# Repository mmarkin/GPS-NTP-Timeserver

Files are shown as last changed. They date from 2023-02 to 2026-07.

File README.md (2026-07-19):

# GPS-NTP-Timeserver
WiFi enabled GPS fed NTP server based on ESP8266 and Arduino framework 

This project adds to the work of Cristiano Monteiro's original GPS-fed NTP timeserver.    
Here is a link to a repository detailing his updated portable version.    
https://github.com/Montecri/GPSTimeServer

I added a second OLED display to show information about what is connected to the server. I also built a custom enclosure for my version 
using walnut, ABS, and tinted transparent acrylic. I tried using a solid wood top but it reduced the GPS reception. The top's ABS panel doesn't 
affect the GPS or WiFi signals. 

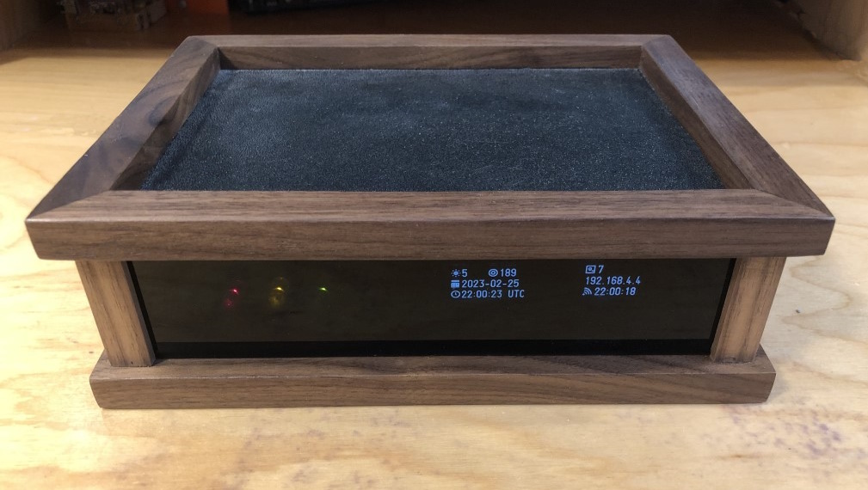
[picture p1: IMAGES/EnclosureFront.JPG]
EnclosureFront_bb-menor


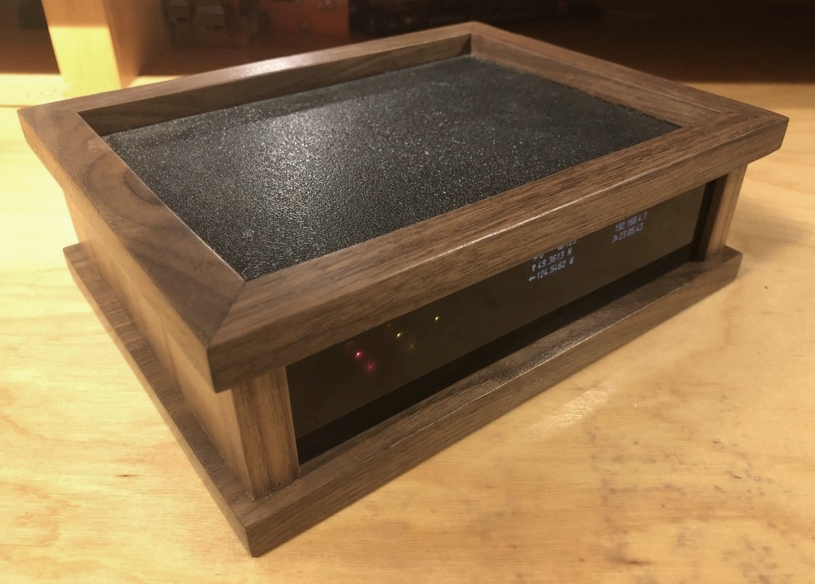
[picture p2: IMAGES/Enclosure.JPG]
Enclosure_bb-menor


As on Cristiano's original version, the first OLED display shows the number of GPS satellites that are "in view," the resolution 
of the position fix, and the UTC time and date. The second OLED display helps to verify that the server responds to the NTP requests. 
Every time an NTP request comes in from a client, i.e., a clock connected to the server's WiFi network, its IP address and the time 
the response was sent are shown on the display. This information remains on the display until the next request arrives. It also shows 
the total number of clients connected. In server mode, ESP8266 microcontrollers can handle up to eight WiFi clients.

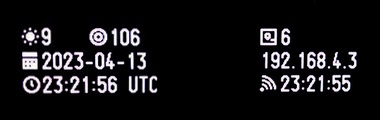
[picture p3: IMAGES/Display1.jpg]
Display1_bb-menor


This version adds a switch so the first display can also show the latitude and longitude. This time server is GPS-based so it 
might as well be able to show where it is located (the exact location has been fuzzed out in the photo). If the location was 
in the southern or eastern hemispheres the arrows would point the opposite way.

Display3_bb-menor

The switch can also turn the displays off since OLED displays can wear out if they are active all the time, especially if they 
show information that doesn't change much. See the schematic diagram below for more details.    

The second display is optional, the code posted here runs without it. However, with multiple clocks it's a handy way to 
make sure they are all connected and being served. 

The I2C address of the second OLED module has to be changed. This is done by relocating a resistor on the module's circuit
board. There is a graphic on the board to show which resistor it is and where it goes for each of the two addresses. For example,
with the recommended SSD1306 modules the address is changed from 0x78 to 0x7A. The resistor is a tiny surface-mount part so 
it requires a bit of delicate soldering to make the change. Also once it's free be careful not to lose it. Don't ask how I know!

The U8g2 library the code uses to drive the OLED displays works with many different displays. 
You just need to use the constructor from the library and the I2C addresses that match the displays being used.
For example, SH1106 modules could also be used. Object definitions for SH1106 modules are included in the definitions.h file. 
To use them comment out the SSD1306 definitions and uncomment the SH1106 definitions. 
The I2C addresses specified in the code may also need to be changed to 0x3C and 0x3D. 

As on Cristiano's original version, the red LED flashes every second when GPS data is available.
The yellow LED shows that WiFi is enabled. The green LED shows that the GPS data is valid and the server's 
internal clock is synchronized with it.

IMG_3050_MOV_AdobeExpress

To use the server, set the clock so it joins the WiFi network specified by the SSID and password in the definitions.h 
file. Also set the clock so the address for the time server it calls is 192.168.4.1 which is the default IP address ESP 
devices use in server mode. The server will assign IP addresses to clients on its network starting with 192.168.4.2.

It is highly recommended to use PlatformIO to compile and edit the code. That way all the libraries needed will be 
downloaded and installed automatically. For those not familiar with PlatformIO, it runs as an extension for Microsoft's VS Code. 
Both are free to download and use without restriction like the Arduino IDE. However, PlatformIO has more professional features 
that make it easier to develop a project like this once you get the hang of using it.
All the files needed for this project have been provided. The code is in two files: definitions.h is in the "includes" directory 
and main.cpp is in the "src" directory. The platformio.ini file is also provided.   

Having said that, the Arduino IDE <i>can</i> be used if desired. Instructions are in the "Using Arduino IDE" file in the "resources" directory.

Parts list:

- Amica NodeMCU (ESP8266 / ESP-12)                   
- DS3231 RTC
- U-blox Neo-6m V2 GPS
- 0.96" OLED Display (SSD1306 or similar. 
  If two are used be sure that it is possible to change the I2C address on one of them.) 
- Hi-Link 5V/3W Power supply
- Mini-360 DC-DC Buck converter
- Red, Green and Yellow LEDs
- Resistors (150, 100 and 150 Ohms respectively for above LEDs)
- Momentary push button switch
- SPDT center off toggle switch

---
<p align="center">  
<b>ATTENTION</b> </p> 

Several DS3231 modules being sold today contain a hazardous design flaw in which it supplies a voltage to the battery cradle 
regardless if it came with a rechargeable battery or not. 
If it came with a CR2032 battery (non-rechargeable) the consequence is that it will swell, explode, or worse. 
If it came with an LIR2032 battery (rechargeable) and the module is fed with 5v, that will generate an unsafe charging voltage for 
that battery.

There are workarounds for this so you do not need to toss your module away, the most popular being the removal of a diode and/or 
resistor.

There is a long discussion on the thread below about the root cause and possible fixes:

https://forum.arduino.cc/t/zs-042-ds3231-rtc-module/268862/33

---

Libraries:

- paulstoffregen/Time@^1.6
- makuna/RTC@^2.4.3
- mikalhart/TinyGPS@0.0.0-alpha+sha.db4ef9c97a
- olikraus/U8g2@^2.28.8

Source code is also based on:<br>
- http://w8bh.net/avr/clock2.pdf
- https://forum.arduino.cc/t/ntp-time-server/192816
- http://www.brettoliver.org.uk/GPS_Time_Server/GPS_Time_Server.htm
- https://www.brettoliver.org.uk/GPS_Time_Server/GPS_Time_Server_v2.htm

---

Schematic diagram

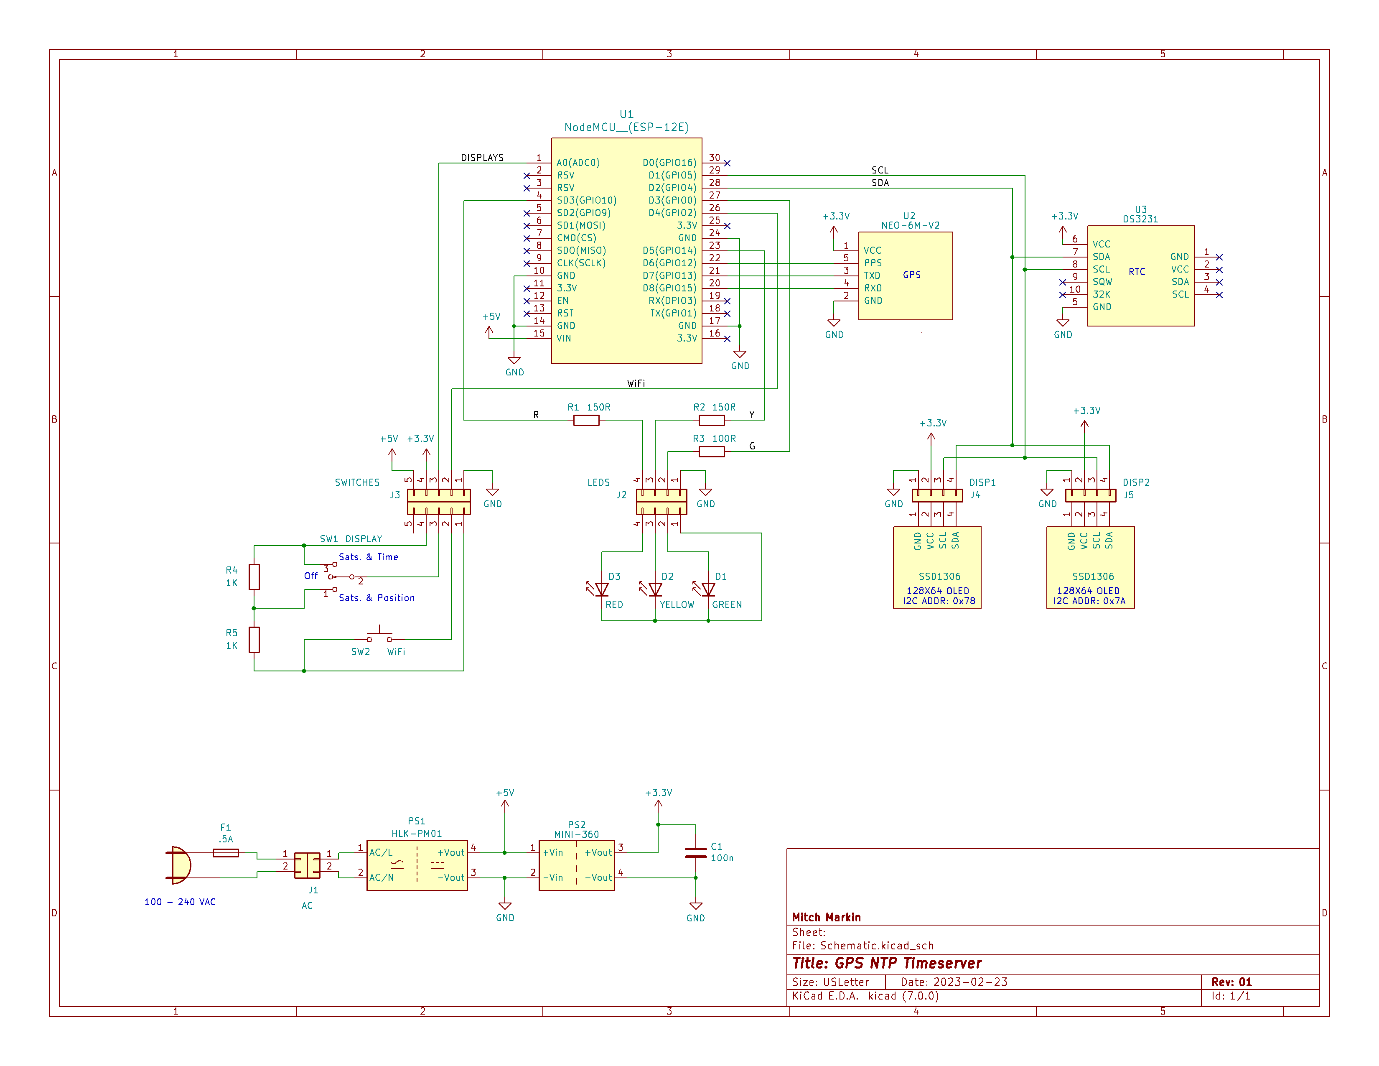
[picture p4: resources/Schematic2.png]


Breadboard layout

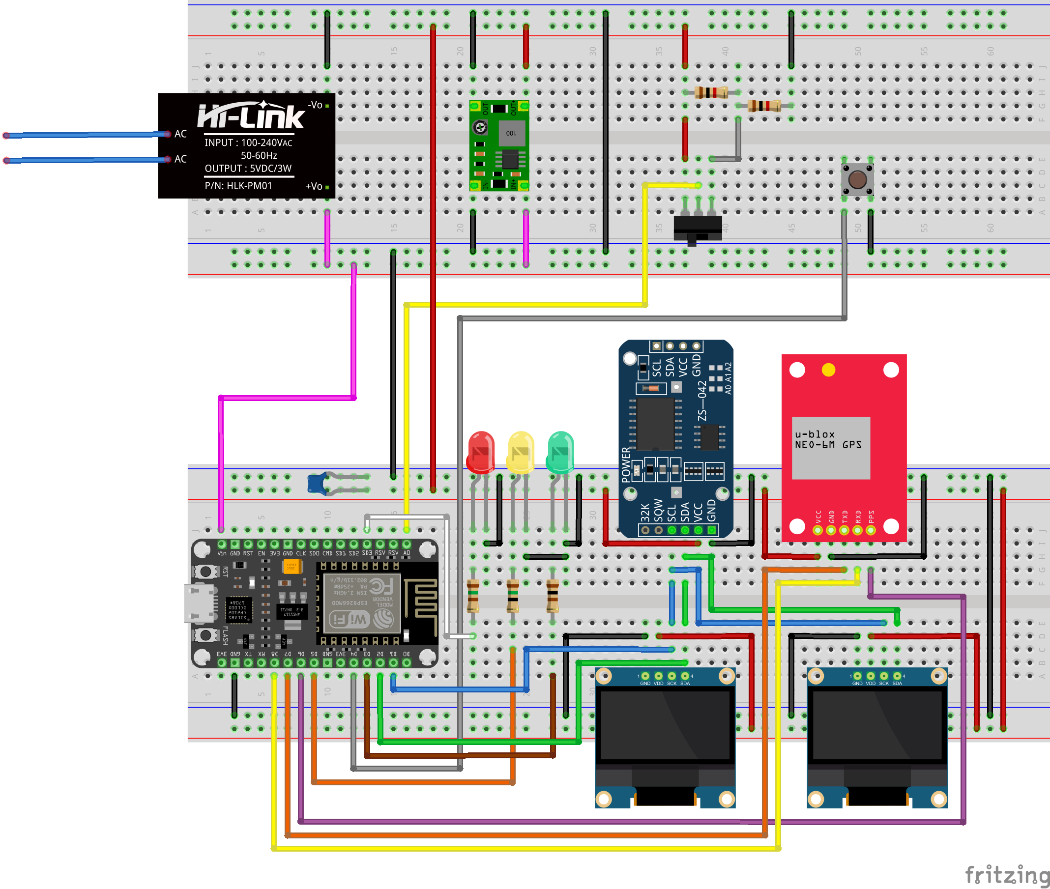
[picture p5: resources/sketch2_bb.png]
sketch_bb-menor


I designed a printed circuit board for the project and had a few made. The Gerber files are in the "resources" folder.
NodeMCU modules come in various sizes. The board was designed for a module that has a 22.86mm (.9 inch) pitch between 
the two rows of pins such as the specified Amica module.  

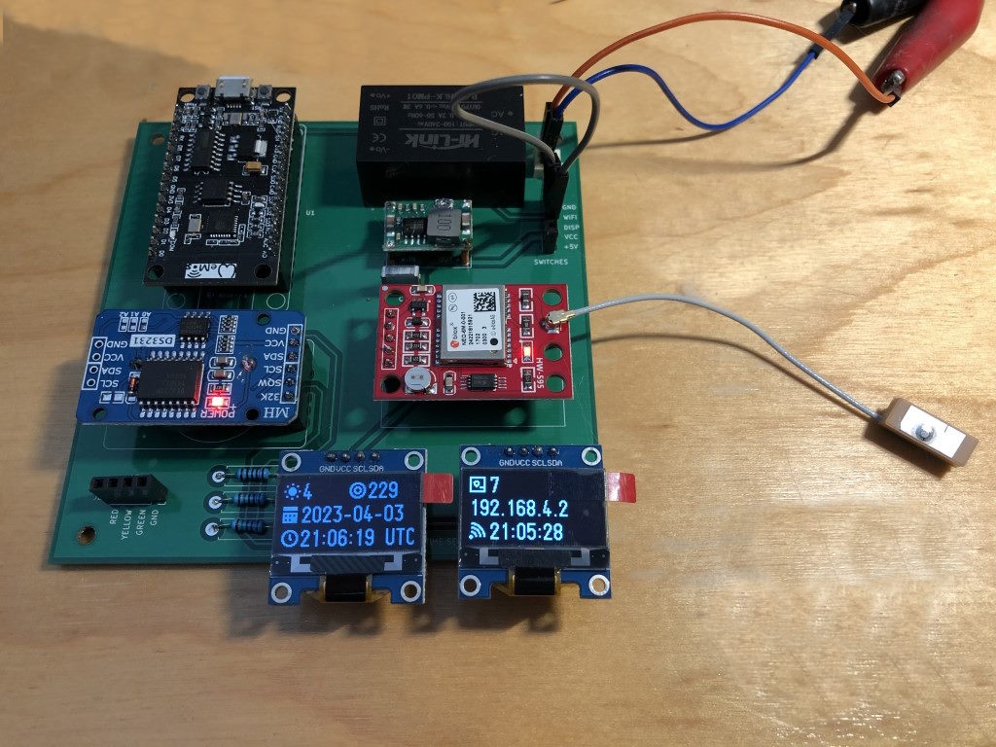
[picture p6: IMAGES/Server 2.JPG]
server2_bb-menor


Here are a couple of photos of the interior of the enclosure.

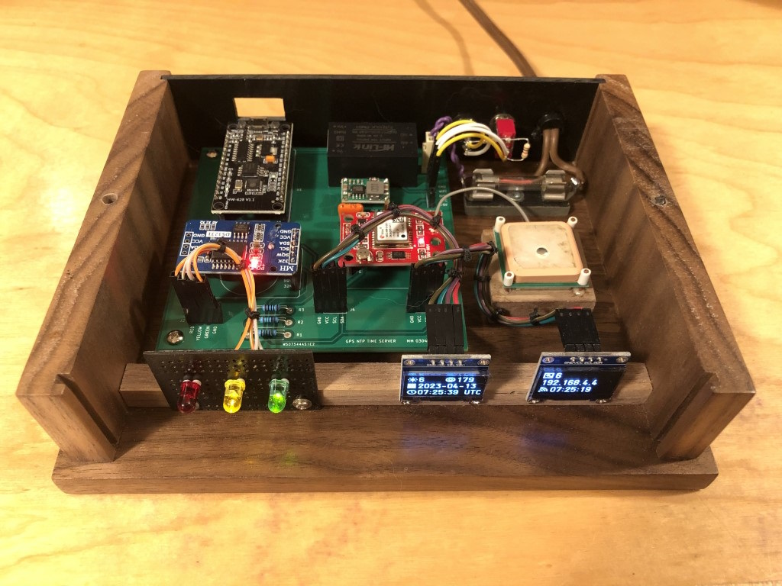
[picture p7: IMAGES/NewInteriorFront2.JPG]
intFront_bb-menor


With the antenna shown the GPS reception is good even indoors not near a window on the ground floor of a two-story 
wood frame building.

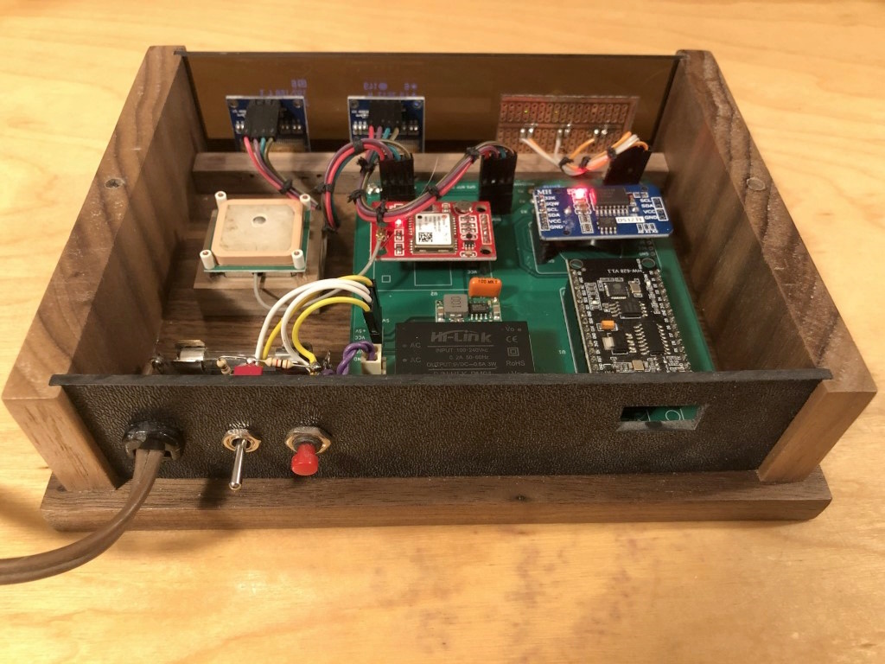
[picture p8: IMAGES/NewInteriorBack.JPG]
intBack_bb-menor


The push button enables or disables the WiFi. It's not really needed here and it could be omitted along with the yellow LED. 
They are carry-overs from Cristiano's version which can be battery-powered, so they are there to conserve power when WiFi isn't needed.
This version is AC-powered and WiFi is enabled by default.
The toggle switch is SPDT with a center-off position. It selects whether time/date/satellite information or the latitude/longitude
received from GPS is shown on the first OLED display. It also turns the displays on and off.

There is also a branch on this repository called PIR Version. It shows a version of this project where a PIR
(passive infrared) module is used to enable both OLED displays only when it detects someone is nearby. 
The pushbutton in that version enables or disables WiFi as usual, 
but a long press switches the first display between time/date/satellite information and the latitude/longitude received from GPS. 

CAD drawing for the enclosure

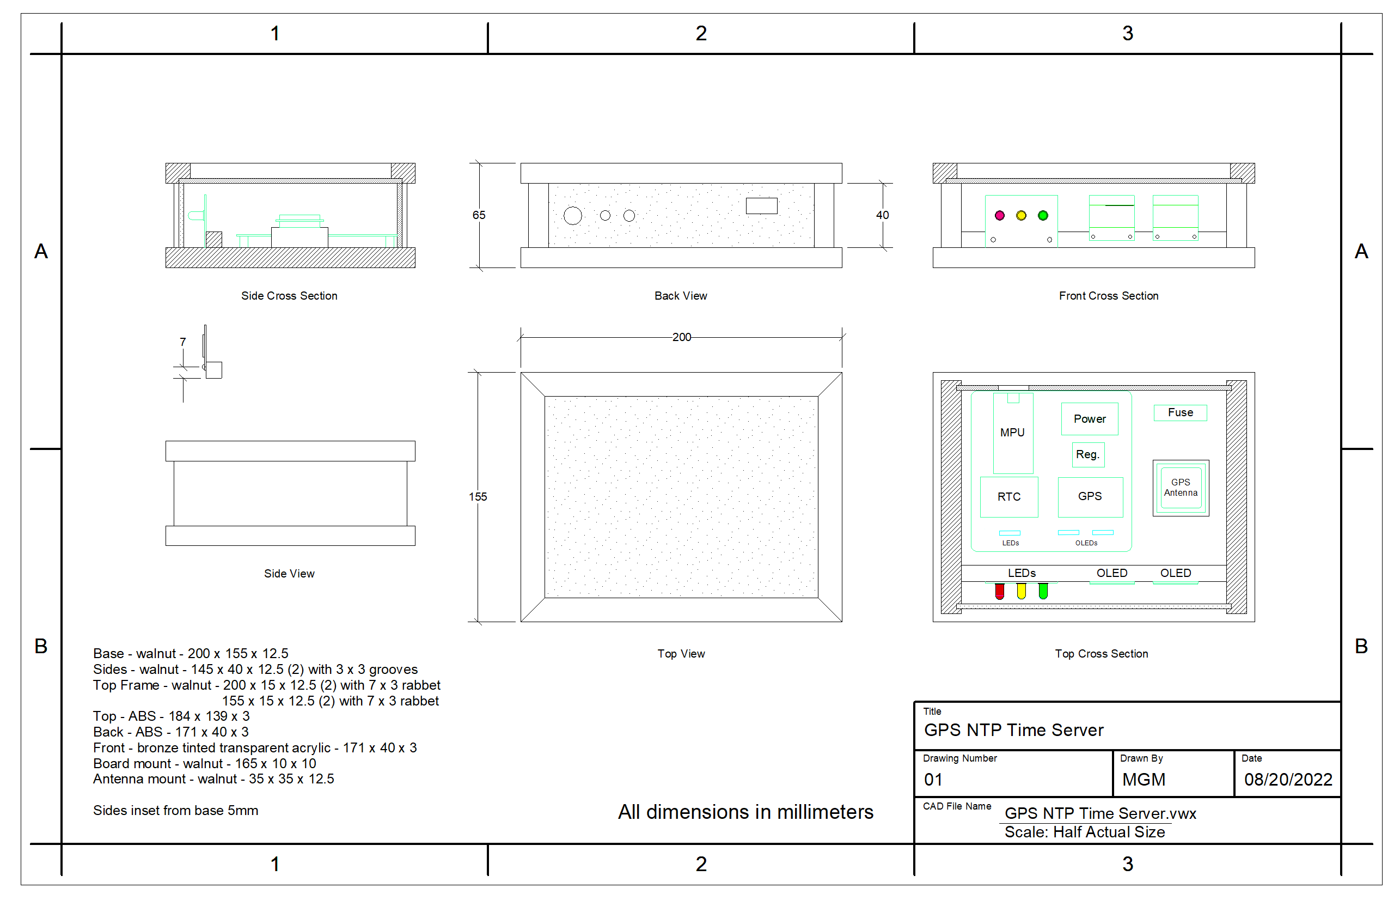
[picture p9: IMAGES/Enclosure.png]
CAD-_bb-menor


More information about Cristiano's original version of this timeserver can be found here:<br>
https://www.linkedin.com/pulse/iot-maker-tale-stratum-1-time-server-built-from-scratch-monteiro/

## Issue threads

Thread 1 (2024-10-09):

Addition of second page function while keeping the motion detector.

Sebastsch, 2024-10-09:
Hello,
Thank you very much for the two-screen project, I had already put together the first version of Cristiano's. I would like to keep the presence detector and be able to access the GPS position with a long press on the wifi button or alternate every 5 seconds for example. Is this possible ?

Sincerely, Sébastien

Sebastsch, 2024-10-10:
Hello Mitch, thank you very much for your quick response. No, unfortunately I have too little programming knowledge. In fact, in my idea, I would have liked to keep the two screens and the PIR, but to be able to access the GPS coordinate information with the directions. I think it would be nice to access it via the wifi button. Thank you very much for your interest in me. Here is the current assembly in photo, unfortunately, I have to improve the wood but I am very poorly equipped☹️.
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

mmarkin, 2024-10-11:
Hi Sébastien
Thanks for the photos. I wasn't sure if you used two displays or not. I see what you want now and I have previous versions of the code that do that.
I posted it in a new branch on this repository. It uses a PIR connected to A0 on the ESP to turn the displays on and off.
Also a short press on the push button turns WiFi on and off.
I just had to add code so a long press switches the first display between the time/satellites information and the latitude/longitude received from GPS.

Your build looks good. I see you had a circuit board made from my files. The case is kind of rough but as long as the server works, that's the main thing! I am fortunate to have a fully equipped woodworking shop at home.

Cheers,
Mitch

Sebastsch, 2024-10-11:
Hi Mitch, Thank you so much for this new feature. I tested the code and everything works perfectly. The button reacts well to a short or long press, no problem, everything is perfect. Thank you for this beautiful work. Very sincerely, Sébastien

mmarkin, 2024-10-11:
Hi Sébastien
Glad the working well on your server. Changing the code was easy because I already had a similar version. I just had to add a bit of code for the long press function.  I have the new code running on my server and the button reacts better than it did with the original code. I'm still using the toggle switch to turn the displays on and off. That way I don't have to modify any hardware.
Thanks for suggesting this modification. It improves the project.
Amicalement,
Mitch

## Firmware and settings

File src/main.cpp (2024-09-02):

/* WiFi enabled GPS NTP server - Cristiano Monteiro <cristianomonteiro@gmail.com> - 06.May.2021
   Based on the work of:
   Bruce E. Hall, W8BH <bhall66@gmail.com> - http://w8bh.net
   and
   https://forum.arduino.cc/u/ziggy2012/summary

   Mitch Markin, 02.Sep.2022:
   date bug from ziggy2012 code fixed,
   unused variables commented out to clear compiler warnings, 
   Brett Oliver's PIR code addded to turn OLED display on and off,
     modified to use switch and voltage divider instead of PIR to select  
     whether time or position is shown on first OLED display
   got rid of string class in display functions,
   ICACHE_RAM_ATTR changed to IRAM_ADDR to clear compiler warnings,
   added second OLED display for client IP information
   03.Apr.2023:
   bug fixes for NTP packet buffer settings suggested by Daniel Rich (sjthespian) 
   31.Aug.2024:
   changes to client display, fixed definitions.h so newer versions of RTC library work
*/

#include "definitions.h"

void setup()
{
  Serial.begin(9600);
  delay(2000);
  Serial.println("\nGPS Time Server");
  Serial.println("Iniciado");  // Portugese for "Initiated" -MM

  pinMode(LOCK_LED, OUTPUT);
  pinMode(PPS_LED, OUTPUT);
  pinMode(WIFI_LED, OUTPUT);
  pinMode(WIFI_BUTTON, INPUT_PULLUP);

  digitalWrite(LOCK_LED, LOW);
  digitalWrite(PPS_LED, LOW);
  digitalWrite(WIFI_LED, LOW);
  
  Wire.begin(D2, D1);    // SDA on ESP pin 4, SCL on ESP pin 5
  Rtc.Begin();
  RtcEeprom.Begin();

  InitOLED();

  ss.begin(9600);        // set GPS baud rate to 9600 bps
  
  // Initialize RTC
  while (!Rtc.GetIsRunning())
  {
    Rtc.SetIsRunning(true);
    DEBUG_PRINTLN(F("RTC had to be force started"));
  }

  DEBUG_PRINTLN(F("RTC started"));

  // Never assume the Rtc was last configured by you, 
  // so just clear them to your needed state
  Rtc.Enable32kHzPin(false);
  Rtc.SetSquareWavePin(DS3231SquareWavePin_ModeNone);

  #ifdef DEBUG
    PrintRTCstatus(); // show RTC diagnostics
  #endif

  SyncWithRTC();                              // start clock with RTC data
  attachInterrupt(PPS_PIN, Isr, RISING);      // enable GPS 1pps interrupt input
  attachInterrupt(WIFI_BUTTON, Btw, FALLING);
  
  ProcessWifi();

  // Startup UDP
  Udp.begin(NTP_PORT);
}

// --------------------------------------------------------------------------------------------------
// MAIN PROGRAM

void loop()
{
  FeedGpsParser();                                    // decode incoming GPS data
  SyncCheck();                                        // synchronize to GPS or RTC
  server.handleClient();
  ProcessNTP();
  UpdateDisplay();                                    // if time has changed, display it

  if (millis() - pps_blink_time > PPS_BLINK_INTERVAL) // if x milliseconds passed, then it's time to switch LED off for blink effect
    digitalWrite(PPS_LED, LOW);

  if (KeyCheck()) // Malabarism to cover mechanical switch debouncing
    ProcessKeypress();  
}

// --------------------------------------------------------------------------------------------------
// Feed currently available data from GPS module into tinyGPS parser

void FeedGpsParser()
{
  while (ss.available()) // look for data from GPS module
  {
    char c = ss.read(); // read in all available chars
    gps.encode(c);      // and feed chars to GPS parser
    //Serial.write(c);    // uncomment for some extra debug info if in doubt about GPS feed
  }
}

// Button ISR debouncing routine, returns true if key pressed

bool KeyCheck()
{
  if (keytick != 0)
  {
    if ((millis() - keytick) > DEBOUNCE_TICKS)
    {
      DEBUG_PRINT(F("KEYTICK: "));
      DEBUG_PRINTLN(keytick);
      keytick = 0;
      DEBUG_PRINTLN(F("KEYCHECK IS TRUE"));
      return true;
    }
  }
  return false;
}

// --------------------------------------------------------------------------------------------------
// WiFi Routines

// Just a little test message. Go to http://192.168.4.1 in a web browser
// connected to this access point to see it

void HandleRoot()
{
  server.send(200, "text/html", "<h1>You are connected.</h1>");
}

void EnableWifi()
{
  // WiFi Initialization
  // You can remove the password parameter if you want the AP to be open

  WiFi.mode(WIFI_AP);
  //WiFi.softAP(ssid, password);            // default, maximum 4 clients
  WiFi.softAP(ssid, password, 1, 0, 8);   // maximum 8 clients -MM

  #ifdef DEBUG
    IPAddress myIP = WiFi.softAPIP();  
    Serial.print(F("AP IP address: "));
    Serial.println(myIP);
  #endif

  server.on("/", HandleRoot);
  server.begin();
  DEBUG_PRINTLN(F("HTTP server started"));
}

void DisableWifi()
{
  server.stop();
  DEBUG_PRINTLN(F("HTTP server stopped"));
  WiFi.softAPdisconnect(true);
  WiFi.enableAP(false);
  WiFi.mode(WIFI_OFF);
  WiFi.forceSleepBegin();
  DEBUG_PRINTLN(F("WiFi disabled")); 
}

void ProcessWifi()
{
  // Toggle WiFi on/off and corresponding LED
  DEBUG_PRINT(F("Status Wifi: "));
  DEBUG_PRINTLN(statusWifi);

  if (statusWifi)
  {
    EnableWifi();
    digitalWrite(WIFI_LED, HIGH);
  }
  else
  {
    DisableWifi();
    digitalWrite(WIFI_LED, LOW);
  }
}

// --------------------------------------------------------------------------------------------------
// SERIAL MONITOR ROUTINES
// These routines print the date/time information to the serial monitor
// Serial monitor must be initialized in setup() before calling

void PrintDigit(int d)
{
  if (d < 10)
  {   
    DEBUG_PRINT('0');
  }   
  DEBUG_PRINT(d);
}

void PrintTime(time_t t)
// Display time and date to serial monitor
{
  PrintDigit(month(t));
  DEBUG_PRINT("-");
  PrintDigit(day(t));
  DEBUG_PRINT("-");
  PrintDigit(year(t));
  DEBUG_PRINT(" ");
  PrintDigit(hour(t));
  DEBUG_PRINT(":");
  PrintDigit(minute(t));
  DEBUG_PRINT(":");
  PrintDigit(second(t));
  DEBUG_PRINTLN(" UTC");
}

// --------------------------------------------------------------------------------------------------
//  RTC SUPPORT
//  These routines add the ability to get and/or set the time from an attached real-time-clock module
//  such as the DS1307 or the DS3231. The module should be connected to the I2C pins (SDA/SCL).

void PrintRTCstatus()
// Send current RTC information to serial monitor
{
  RtcDateTime Now = Rtc.GetDateTime();
  time_t t = Now.Unix32Time();
  if (t)
  {
    DEBUG_PRINT("PrintRTCstatus: ");
    DEBUG_PRINTLN("Called PrintTime from PrintRTCstatus");
    #ifdef DEBUG
      PrintTime(t);
    #endif
  }
  else
  {   
    DEBUG_PRINTLN("ERROR: cannot read the RTC.");
  }   
}

// Update RTC from current system time
void SetRTC(time_t t)
{
  RtcDateTime timeToSet;

  timeToSet.InitWithUnix32Time(t);

  Rtc.SetDateTime(timeToSet);
  if (Rtc.LastError() == 0)
  {
    DEBUG_PRINT("SetRTC: ");
    DEBUG_PRINTLN("Called PrintTime from SetRTC");
    #ifdef DEBUG
      PrintTime(t);
    #endif
  }
  else
  {   
    DEBUG_PRINT("ERROR: cannot set RTC time");
  }   
}

// Use this routine to manually set the RTC to a specific UTC time.
// Since time is automatically set from GPS, this routine is mainly for
// debugging purposes.  Change numeric constants to the time desired.

void ManuallySetRTC()
{
  //  tmElements_t tm;
  //  tm.Year   = 2017 - 1970;      // year in unix years
  //  tm.Month  = 5;
  //  tm.Day    = 31;
  //  tm.Hour   = 5;
  //  tm.Minute = 59;
  //  tm.Second = 30;
  //  SetRTC(makeTime(tm));         // set RTC to desired time
}

// Keep the RTC time updated by setting it every (RTC_UPDATE_INTERVAL) seconds
// should only be called when system time is known to be good, such as in a GPS sync event

void UpdateRTC()
{
  time_t t = now();                            // get current time
  if ((t - lastSetRTC) >= RTC_UPDATE_INTERVAL) // is it time to update RTC internal clock?
  {
    DEBUG_PRINT("Called SetRTC from UpdateRTC with ");
    DEBUG_PRINTLN(t);
    SetRTC(t);      // set RTC with current time
    lastSetRTC = t; // remember time of this event
  }
}

// --------------------------------------------------------------------------------------------------
// OLED SPECIFIC ROUTINES
// These routines are used to display time and/or date information on the OLED display

void InitOLED()
{
  u8g2_1.setI2CAddress(DISPLAY_1_ADDR);
  u8g2_1.begin();
  u8g2_1.setContrast(2);    // you can play with this to try to equalize brightness of both displays
                                // but it doesn't have much effect -MM
           
  u8g2_2.setI2CAddress(DISPLAY_2_ADDR);
  u8g2_2.begin();
  u8g2_2.setContrast(255); 
}

void ShowDate(time_t t)
{
  int y = year(t);
  int m = month(t);
  int d = day(t);
  
  char buffer[11];
  snprintf(buffer, 11, (PGM_P)F("%.4i-%.2i-%.2i"), y, m, d);  

  u8g2_1.setFont(u8g2_font_open_iconic_all_2x_t);   
  u8g2_1.drawGlyph(0, 41, 107);

  u8g2_1.setFont(u8g2_font_logisoso16_tf);   // choose a suitable font
  u8g2_1.drawStr(18, 41, buffer);

  DEBUG_PRINTLN("UpdateDisplay");
}

void ShowTime(time_t t)
{
  int h = hour(t);
  int m = minute(t);
  int s = second(t);  
  char buffer[13];
  
  snprintf(buffer, 13, (PGM_P)F("%.2i:%.2i:%.2i UTC"), h, m, s); 

  u8g2_1.setFont(u8g2_font_open_iconic_all_2x_t);
  u8g2_1.drawGlyph(0, 64, 123);

  u8g2_1.setFont(u8g2_font_logisoso16_tf);     
  u8g2_1.drawStr(18, 64, buffer); 
}

void ShowSatellites()
{
  uint8_t sats;
  if (gps.satellites() != 255) sats = gps.satellites();
  else sats = 0;

  uint32_t resol;
  if (gpsLocked) resol = gps.hdop();
  else resol = 0;

  u8g2_1.setFont(u8g2_font_open_iconic_all_2x_t);
  u8g2_1.drawGlyph(0, 18, 259);
  u8g2_1.drawGlyph(64, 18, 263);

  u8g2_1.setFont(u8g2_font_logisoso16_tf);    
  u8g2_1.setCursor(18, 18);
  u8g2_1.print(sats);
  u8g2_1.setCursor(82, 18);
  u8g2_1.print(resol);
}

void ShowPosition()
{  
  if (latitude < 0.0) 
  {
    u8g2_1.setFont(u8g2_font_open_iconic_all_2x_t);
    u8g2_1.drawGlyph(0, 41, 79);
    u8g2_1.setFont(u8g2_font_logisoso16_tf); 
    u8g2_1.setCursor(18, 41);
    u8g2_1.print(abs(latitude), 4);
    u8g2_1.print(" S"); 
  }  
  else
  {
    u8g2_1.setFont(u8g2_font_open_iconic_all_2x_t);
    u8g2_1.drawGlyph(0, 41, 82);
    u8g2_1.setFont(u8g2_font_logisoso16_tf); 
    u8g2_1.setCursor(18, 41);
    u8g2_1.print(abs(latitude), 4);
    u8g2_1.print(" N"); 
  }  

  if (longitude < 0.0) 
  {
    u8g2_1.setFont(u8g2_font_open_iconic_all_2x_t);
    u8g2_1.drawGlyph(0, 64, 80);
    u8g2_1.setFont(u8g2_font_logisoso16_tf); 
    u8g2_1.setCursor(18, 64);
    u8g2_1.print(abs(longitude), 4);
    u8g2_1.print(" W"); 
  }  
  else
  {
    u8g2_1.setFont(u8g2_font_open_iconic_all_2x_t);
    u8g2_1.drawGlyph(0, 64, 81);
    u8g2_1.setFont(u8g2_font_logisoso16_tf); 
    u8g2_1.setCursor(18, 64);
    u8g2_1.print(abs(longitude), 4);
    u8g2_1.print(" E"); 
  }  
}

void ShowTitle()
{
  u8g2_1.setFont(u8g2_font_logisoso16_tf);   
  u8g2_1.setCursor(0, 18);
  u8g2_1.print("GPS NTP Sync");
}  

void ShowClient()
{
  char buffer[16]; 
  uint8_t stationCount = wifi_softap_get_station_num();   

  u8g2_2.setFont(u8g2_font_open_iconic_all_2x_t);
  u8g2_2.drawGlyph(65, 18, 208);    // Server icon
  u8g2_2.drawGlyph(0, 64, 247);     // WiFi icon

  u8g2_2.setFont(u8g2_font_logisoso16_tf);

  u8g2_2.setCursor(0, 18);
  u8g2_2.print("Clients");

  u8g2_2.setCursor(85, 18);
  u8g2_2.print(stationCount);

  u8g2_2.setCursor(0, 41);
  u8g2_2.print(clientIP);

  snprintf(buffer, 12, "%.2i:%.2i:%.2i", hour(lastFix), minute(lastFix), second(lastFix));  
  u8g2_2.drawStr(20, 64, buffer);                                 
}

void ShowSyncFlag()
{
  if (gpsLocked) digitalWrite(LOCK_LED, HIGH);
  else digitalWrite(LOCK_LED, LOW);
}

//  Call this from the main loop
//  Updates display if time has changed

void UpdateDisplay()
{
  time_t t = now();         // get current time
  if (t != displayTime)     // has time changed?
  {
    displayTime = t;        // save current display value
    ShowSyncFlag();         // show if display is in GPS sync

    uint16_t PIRValue = analogRead(A0);

    if (PIRValue < 340)         
    {
      u8g2_1.setPowerSave(1);   // turn displays off
      u8g2_2.setPowerSave(1);     
    } 
    else if (PIRValue < 680)    
    {
      u8g2_1.setPowerSave(0);   // turn displays on, show position
      u8g2_2.setPowerSave(0);

      u8g2_1.clearBuffer();    
      ShowSatellites();
      ShowPosition();                 
      u8g2_1.sendBuffer();      

      u8g2_2.clearBuffer();       
      ShowClient();
      u8g2_2.sendBuffer();    
    }
    else
    {
      u8g2_1.setPowerSave(0);   // turn displays on, show time and date
      u8g2_2.setPowerSave(0);

      u8g2_1.clearBuffer();    
      ShowSatellites();
      ShowDate(t);
      ShowTime(t);           
      u8g2_1.sendBuffer();     

      u8g2_2.clearBuffer();     
      ShowClient();
      u8g2_2.sendBuffer();   
    }

    /*
    if (PIRValue < 500)         
    {
      u8g2_1.setPowerSave(1);   // turn displays off
      u8g2_2.setPowerSave(1);     
    } 
    else
    {
      u8g2_1.setPowerSave(0);   // turn displays on
      u8g2_2.setPowerSave(0);
      

    u8g2_1.clearBuffer();     
    ShowSatellites();
    ShowDate(t);
    ShowTime(t);           
    u8g2_1.sendBuffer();     

    u8g2_2.clearBuffer();     
    ShowClient();
    u8g2_2.sendBuffer();   
    */
   
    DEBUG_PRINTLN("Called PrintTime from UpdateDisplay");   

    #ifdef DEBUG
      PrintTime(t); // copy time to serial monitor
    #endif
  }
}

// --------------------------------------------------------------------------------------------------
// TIME SYNCHONIZATION ROUTINES
// These routines will synchonize time with GPS and/or RTC as necessary.
// Sync with GPS occurs when the 1pps interrupt signal from the GPS goes high.
// GPS synchonization events are attempted every (SYNC_INTERVAL) seconds.
// If a valid GPS signal is not received within (SYNC_TIMEOUT) seconds, the clock is synchonized
// with RTC instead.  The RTC time is updated with GPS data once every 24 hours.

void SyncWithGPS()
{
  int y;
  //byte h, m, s, mon, d, hundredths;    // hundredths is not used here
  byte h, m, s, mon, d;
  unsigned long age;
  gps.crack_datetime(&y, &mon, &d, &h, &m, &s, NULL, &age); // get time from GPS
  gps.f_get_position(&latitude, &longitude);

  //if (age < 1000 or age > 3000)        // dont use data older than 1 second
  if (age < 1000)
  {
    setTime(h, m, s, d, mon, y);       // copy GPS time to system time
    DEBUG_PRINT("Time from GPS: ");
    DEBUG_PRINT(h);
    DEBUG_PRINT(":");
    DEBUG_PRINT(m);
    DEBUG_PRINT(":");
    DEBUG_PRINTLN(s);
    adjustTime(1);                     // 1pps signal = start of next second
    syncTime = now();                  // remember time of this sync
    gpsLocked = true;                  // set flag that time is reflects GPS time
    UpdateRTC();                       // update internal RTC clock periodically
    DEBUG_PRINTLN("GPS synchronized"); // send message to serial monitor   
  }
  else
  {
    DEBUG_PRINT("Age: ");
    DEBUG_PRINTLN(age);
  }  
}

void SyncWithRTC()
{
  RtcDateTime time = Rtc.GetDateTime();
  long int a = time.Unix32Time();
  setTime(a); // set system time from RTC
  DEBUG_PRINT("SyncFromRTC: ");
  DEBUG_PRINTLN(a);
  syncTime = now();                          // remember time of this sync event
  DEBUG_PRINTLN("Synchronized from RTC");    // send message to serial monitor
}

void SyncCheck()
// Manage synchonization of clock to GPS module
// First, check to see if it is time to synchonize
// Do time synchonization on the 1pps signal
// This call must be made frequently (keep in main loop)
{
  unsigned long timeSinceSync = now() - syncTime;    // how long has it been since last sync?
  if (pps && (timeSinceSync >= SYNC_INTERVAL))
  { // is it time to sync with GPS yet?
    DEBUG_PRINTLN("Called SyncWithGPS from SyncCheck");
    SyncWithGPS(); // yes, so attempt it.
  }
  pps = 0;                              // reset 1-pulse-per-second flag, regardless
  if (timeSinceSync >= SYNC_TIMEOUT)    // GPS sync has failed
  {
    gpsLocked = false; // flag that clock is no longer in GPS sync
    DEBUG_PRINTLN("Called SyncWithRTC from SyncCheck");
    SyncWithRTC(); // sync with RTC instead
  }
}

void IRAM_ATTR 
Isr()           // INTERRUPT SERVICE REQUEST
{
  pps = 1;                     // flag the 1pps input signal
  digitalWrite(PPS_LED, HIGH); // light up LED pps monitor
  pps_blink_time = millis();   // capture time in order to turn LED off so we can get the blink effect every x milliseconds - On loop
  DEBUG_PRINTLN("pps");
}

// Handle button pressed interrupt
void IRAM_ATTR Btw()           // INTERRUPT SERVICE REQUEST
{
  keytick = millis();
  DEBUG_PRINTLN(F("BUTTON PRESSED!"));
}

void ProcessKeypress()
{
  if (statusWifi)
    statusWifi = 0;
  else
    statusWifi = 1;

  ProcessWifi();
  DEBUG_PRINTLN(F("BUTTON CLICK PROCESSED!"));
}

// --------------------------------------------------------------------------------------------------

void ProcessNTP()
{
  // If there's data available, read a packet                            
  int packetSize = Udp.parsePacket();
  if (packetSize)
  {
    Udp.read(packetBuffer, NTP_PACKET_SIZE);
    IPAddress Remote = Udp.remoteIP();
    clientIP = Udp.remoteIP();                 // store in global variable for OLED display
    int PortNum = Udp.remotePort();

    #ifdef DEBUG
      Serial.println();  
      Serial.print("Received UDP packet size ");
      Serial.println(packetSize);
      Serial.print("From ");

      for (int i = 0; i < 4; i++)
      {
        Serial.print(Remote[i], DEC);
        if (i < 3)
        {
          Serial.print(".");
        }
      }
      Serial.print(", port ");
      Serial.print(PortNum);

      //byte LIVNMODE = packetBuffer[0];
      Serial.print("  LI, Vers, Mode :");
      Serial.print(packetBuffer[0], HEX);

      //byte STRATUM = packetBuffer[1];
      Serial.print("  Stratum :");
      Serial.print(packetBuffer[1], HEX);

      //byte POLLING = packetBuffer[2];
      Serial.print("  Polling :");
      Serial.print(packetBuffer[2], HEX);

      //byte PRECISION = packetBuffer[3];
      Serial.print("  Precision :");
      Serial.println(packetBuffer[3], HEX);

      for (int z = 0; z < NTP_PACKET_SIZE; z++)
      {
        Serial.print(packetBuffer[z], HEX);
        if (((z + 1) % 4) == 0)
        {
          Serial.println();
        }
      }
      Serial.println();
    #endif

    packetBuffer[0] = 0b00100100;         // 00 (no leapsecond indicated), 100 (version 4), 100 (server mode)
    if (gpsLocked) packetBuffer[1] = 1;   // stratum 1 if synced with GPS
    else  packetBuffer[1] = 16;           // stratum 16 if not synced
    packetBuffer[2] = 6;                  // polling minimum
    packetBuffer[3] = 0xFA;               // precision

    packetBuffer[4] = 0;                  // root delay
    packetBuffer[5] = 0;
    packetBuffer[6] = 8;
    packetBuffer[7] = 0;

    packetBuffer[8] = 0;                  // root dispersion
    packetBuffer[9] = 0;
    packetBuffer[10] = 0xC;
    packetBuffer[11] = 0;

    uint32_t timestamp, tempval;
    const uint32_t seventyYears = 2208988800UL;    // to convert Unix time to NTP 
    time_t t = now();
    lastFix = t;    
    timestamp = t + seventyYears;    

    #ifdef DEBUG
      Serial.print("Timestamp: ");
      Serial.print(hour(t));    Serial.print(":");
      Serial.print(minute(t));  Serial.print(":");
      Serial.print(second(t));  Serial.print("   ");
      Serial.println(timestamp);    
    #endif

    tempval = timestamp;

    // Set refid 

    if (gpsLocked) 
    {    
      packetBuffer[12] = 71; // "G";
      packetBuffer[13] = 80; // "P";
      packetBuffer[14] = 83; // "S";
      packetBuffer[15] = 0;  // "0";
    } 
    else 
    {
      IPAddress myIP = WiFi.softAPIP();
      packetBuffer[12] = myIP[0]; 
      packetBuffer[13] = myIP[1];
      packetBuffer[14] = myIP[2];
      packetBuffer[15] = myIP[3]; 
    }

    // Reference timestamp

    packetBuffer[16] = (tempval >> 24) & 0xFF;
    tempval = timestamp;
    packetBuffer[17] = (tempval >> 16) & 0xFF;
    tempval = timestamp;
    packetBuffer[18] = (tempval >> 8) & 0xFF;
    tempval = timestamp;
    packetBuffer[19] = (tempval) & 0xFF;

    packetBuffer[20] = 0;
    packetBuffer[21] = 0;
    packetBuffer[22] = 0;
    packetBuffer[23] = 0;

    // Copy originate timestamp from incoming UDP transmit timestamp

    packetBuffer[24] = packetBuffer[40];
    packetBuffer[25] = packetBuffer[41];
    packetBuffer[26] = packetBuffer[42];
    packetBuffer[27] = packetBuffer[43];
    packetBuffer[28] = packetBuffer[44];
    packetBuffer[29] = packetBuffer[45];
    packetBuffer[30] = packetBuffer[46];
    packetBuffer[31] = packetBuffer[47];

    // Receive timestamp
    
    packetBuffer[32] = (tempval >> 24) & 0xFF;
    tempval = timestamp;
    packetBuffer[33] = (tempval >> 16) & 0xFF;
    tempval = timestamp;
    packetBuffer[34] = (tempval >> 8) & 0xFF;
    tempval = timestamp;
    packetBuffer[35] = (tempval) & 0xFF;

    packetBuffer[36] = 0;
    packetBuffer[37] = 0;
    packetBuffer[38] = 0;
    packetBuffer[39] = 0;

    // Transmit timestamp

    packetBuffer[40] = (tempval >> 24) & 0xFF;
    tempval = timestamp;
    packetBuffer[41] = (tempval >> 16) & 0xFF;
    tempval = timestamp;
    packetBuffer[42] = (tempval >> 8) & 0xFF;
    tempval = timestamp;
    packetBuffer[43] = (tempval) & 0xFF;

    packetBuffer[44] = 0;
    packetBuffer[45] = 0;
    packetBuffer[46] = 0;
    packetBuffer[47] = 0;

    // Reply to the IP address and port that sent the NTP request        
    
    Udp.beginPacket(Remote, PortNum);
    Udp.write(packetBuffer, NTP_PACKET_SIZE);
    Udp.endPacket();
  }
}

// --------------------------------------------------------------------------------------------------
//  END

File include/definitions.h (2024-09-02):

#include <Arduino.h>
#include <U8g2lib.h>        // OLED
#include <WiFiUdp.h>        // UDP functionality
#define NTP_PORT 123        // Time Server Port

#include <RtcDS3231.h>      // RTC functions
#include <EepromAT24C32.h>  // We will use clock's eeprom to store config

// Create a WiFi access point and provide a web server on it 

#include <ESP8266WiFi.h>
#include <WiFiClient.h>
#include <ESP8266WebServer.h>

#define APSSID "GPSTimeServer" // AP SSID - set to desired server name
#define APPSK "thereisnospoon" // AP password - set to desired server password
#define PPS_PIN D6             // Pin on which 1PPS line is attached
#define SYNC_INTERVAL 10       // time, in seconds, between GPS sync attempts
#define SYNC_TIMEOUT 30        // time(sec) without GPS input before error
#define RTC_UPDATE_INTERVAL 30 // time(sec) between RTC SetTime events
#define PPS_BLINK_INTERVAL 50  // Set time pps LED should be on for blink effect
#define DISPLAY_1_ADDR 0x78
#define DISPLAY_2_ADDR 0x7A

#define LOCK_LED D3
#define PPS_LED 10
#define WIFI_LED D5
#define WIFI_BUTTON D4

#include <SoftwareSerial.h>
#include <TimeLib.h>     // Time functions  https://github.com/PaulStoffregen/Time
#include <TinyGPS.h>     // GPS parsing     https://github.com/mikalhart/TinyGPS
#include <Wire.h>        // OLED and DS3231 
//#include <RtcDS3231.h>    Can't include RTC functions here, has to be before EepromAT24C32.h 
                         // so newer versions of RTC library work

RtcDS3231<TwoWire> Rtc(Wire);
EepromAt24c32<TwoWire> RtcEeprom(Wire);
 
// The U8G2 library has many constuctors. Use the one that's appropriate for your displays -MM

U8G2_SSD1306_128X64_NONAME_F_HW_I2C u8g2_1(U8G2_R0, U8X8_PIN_NONE);    // OLED display library parameters
U8G2_SSD1306_128X64_NONAME_F_HW_I2C u8g2_2(U8G2_R0, U8X8_PIN_NONE);    //   (rotation, reset pin) 

//U8G2_SH1106_128X64_NONAME_F_HW_I2C u8g2_1(U8G2_R0, U8X8_PIN_NONE); 
//U8G2_SH1106_128X64_NONAME_F_HW_I2C u8g2_2(U8G2_R0, U8X8_PIN_NONE); 

TinyGPS gps;
SoftwareSerial ss(D7, D8);              // serial GPS handler
ESP8266WebServer server(80);
WiFiUDP Udp;                            // an Ethernet UDP instance

static const int NTP_PACKET_SIZE = 48;
byte packetBuffer[NTP_PACKET_SIZE];     // buffers for receiving and sending data
time_t displayTime = 0;                 // time that is currently displayed
time_t syncTime = 0;                    // time of last GPS or RTC synchronization
time_t lastSetRTC = 0;                  // time that RTC was last set
volatile int pps = 0;                   // GPS one-pulse-per-second flag
time_t dstStart = 0;                    // start of DST in unix time
time_t dstEnd = 0;                      // end of DST in unix time
time_t lastFix;                         // time of most recent NTP response
bool gpsLocked = false;                 // indicates recent sync with GPS
int currentYear = 0;                    // used for DST
long int pps_blink_time = 0;
IPAddress clientIP;                     // address of most recent client
byte statusWifi = 1;
float latitude, longitude;
const char *ssid = APSSID;
const char *password = APPSK;

// ISR Debounce
#define DEBOUNCE_TICKS 150    // use 150ms debounce time
word keytick = 0;             // record time of keypress

//#define DEBUG     // comment this in order to remove debug code from release version

#ifdef DEBUG
#define DEBUG_PRINT(x) Serial.print(x);
#define DEBUG_PRINTDEC(x) Serial.print(x, DEC);
#define DEBUG_PRINTLN(x) Serial.println(x);
#else
#define DEBUG_PRINT(x)
#define DEBUG_PRINTDEC(x)
#define DEBUG_PRINTLN(x)
#endif

// Function prototypes

bool KeyCheck();
void HandleRoot();
void EnableWifi();
void DisableWifi();
void ProcessWifi();
void PrintDigit(int d);
void PrintTime(time_t t);
void PrintRTCstatus();
void SetRTC(time_t t);
void ManuallySetRTC();
void UpdateRTC();
void ShowDate(time_t t);
void ShowTime(time_t t);
void ShowClient();
void ShowSatellites();
void ShowPosition();
void ShowTitle();
void ShowSyncFlag();
void SyncWithGPS();
void SyncWithRTC();
void SyncCheck();
void IRAM_ATTR Isr();
void IRAM_ATTR Btw();
void ProcessKeypress();
void FeedGpsParser();
void UpdateDisplay();
void ProcessNTP();
void InitOLED();

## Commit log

2023-04-04 Update main.cpp
    bug fixes for NTP packet buffer settings suggested by sjthespian
    [main.cpp]
2023-04-04 Create Gerbers
2023-04-04 Create Gerber Files
2023-04-19 Create Arduino IDE
2023-04-19 Update Arduino IDE
2023-04-19 Update and rename Arduino IDE to Using Arduino IDE
2023-04-19 Update Using Arduino IDE
